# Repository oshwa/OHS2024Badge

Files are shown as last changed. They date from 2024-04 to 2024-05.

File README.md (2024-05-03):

# OHS 2024 Badge

Hack your OHS 2024 Badge! There will be a hacking station during the summit to modify the badge code (we'll supply some programmers). If you want to add some of your own hardware to the badge, bring some tools and components to make your own SAO!

## Badge Overview

The front and back of the badge:

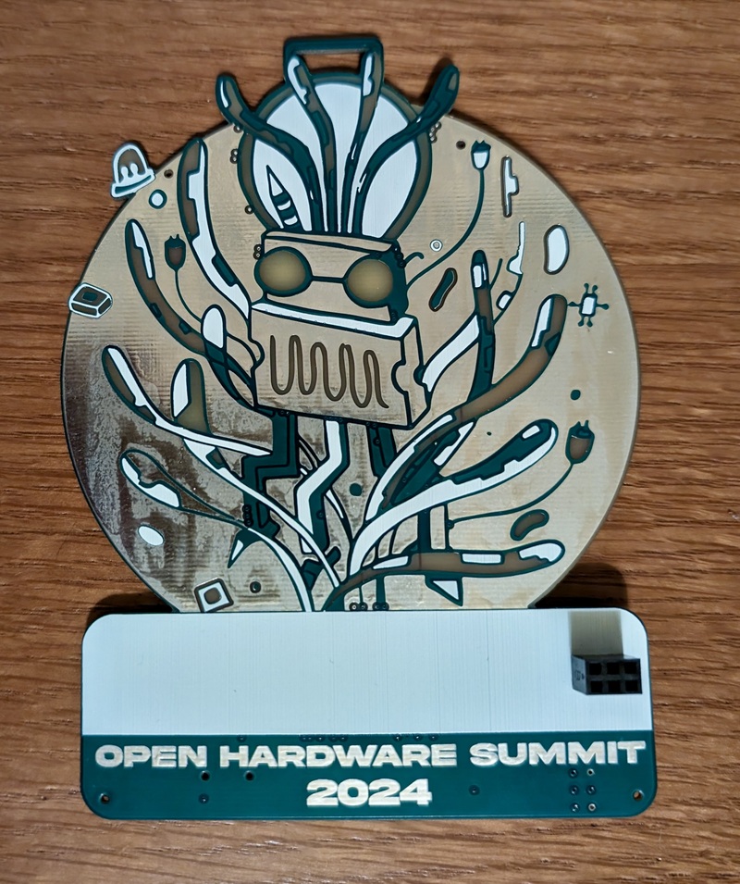
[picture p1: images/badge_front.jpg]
Front view of Open Hardware Summit 2024 Badge PCB.

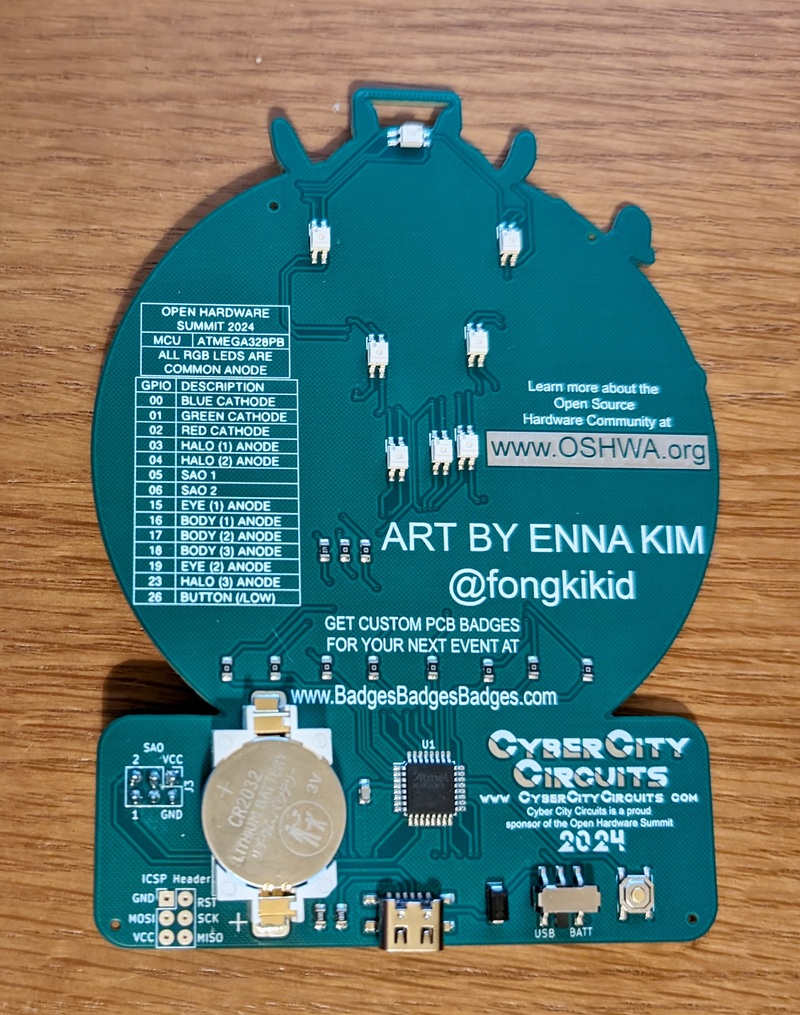
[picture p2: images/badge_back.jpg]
Back view of Open Hardware Summit 2024 Badge PCB.


The badge features some amazing art by [Enna Kim](https://www.instagram.com/fongkikid/) and was created by [Cyber City Circuits](https://cybercitycircuits.com/).

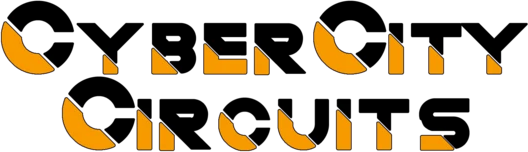
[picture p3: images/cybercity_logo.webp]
Cyber City Circuits Logo.


The badge features:

- Eight RGB LEDs that light up the eyes, ring and body of the lil' guy
- Preloaded LED animations - use the push button to cycle through them all!
- Switch between battery and USB power
- [SAO connector](https://hackaday.io/project/175182-simple-add-ons-sao) with power and two GPIO pins for badge addons!

## Getting Started

### Choose Your Programmer

The badge is compatible with Arduino IDE. However, there is no USB data connection so the badge has to have an external programmer to modify the code on the microcontroller. An easy programmer to use is the [USBtinyISP](https://learn.adafruit.com/usbtinyisp/overview) which is affordable and open source. Here is a version of the board sold on Amazon:

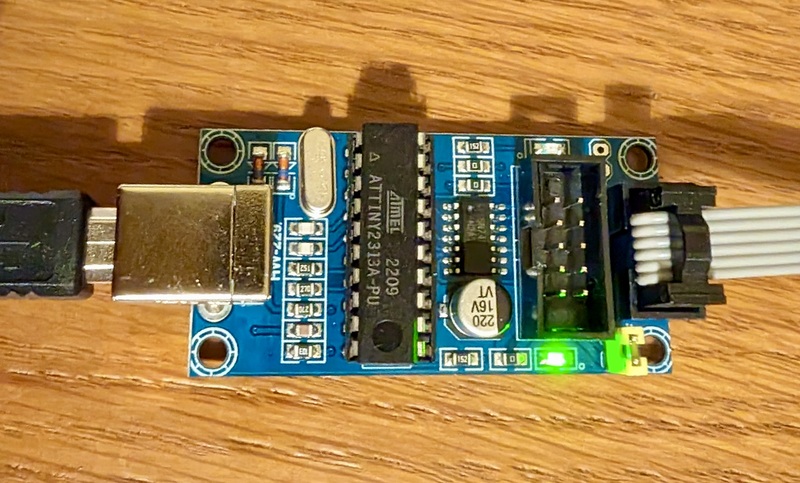
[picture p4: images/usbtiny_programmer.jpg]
USBtinyISP programmer.


You may need to install drivers on Windows: [https://learn.adafruit.com/usbtinyisp/download](https://learn.adafruit.com/usbtinyisp/download)

### Setup Arduino IDE

The board uses [MiniCore](https://github.com/MCUdude/MiniCore) with the [Arduino IDE](https://www.arduino.cc/en/software). Follow these instructions to install MiniCore:
[https://github.com/MCUdude/MiniCore?tab=readme-ov-file#how-to-install](https://github.com/MCUdude/MiniCore?tab=readme-ov-file#how-to-install)

Clone this repository and open [OHS2024Badge.ino](OHS2024Badge.ino) in the Arduino IDE.

Connect the USBtinyISP programmer to your computer.

From the *Tools* menu select:

- Board: -> MiniCore -> ATmega328
- Clock: -> Internal 8 MHz
- Variant: -> 328PB
- Programmer: -> USBtinyISP

**NOTE**: You do not need to set the port, the programmer will be seen as a USB device by the operating system.

Build the code by selecting from the menu *Sketch -> Verify/Compile*. If all goes well, the code should compile without any errors.

### Upload With a Programmer

Now for the tricky part: We have to hold the programmer spring-loaded (pogo) pins directly onto the exposed ICSP pads on the back of the Badge. Make sure the pins from the programmer line up with the pads on the badge. There are often labels written directly on the PCBs that tell you which pin is which. If the badge becomes powered by the programmer, you know the connection is being made properly. The following pictures show how the 2x3 pin header is arranged and how to hold spring-loaded pins directly onto the badge PCB:

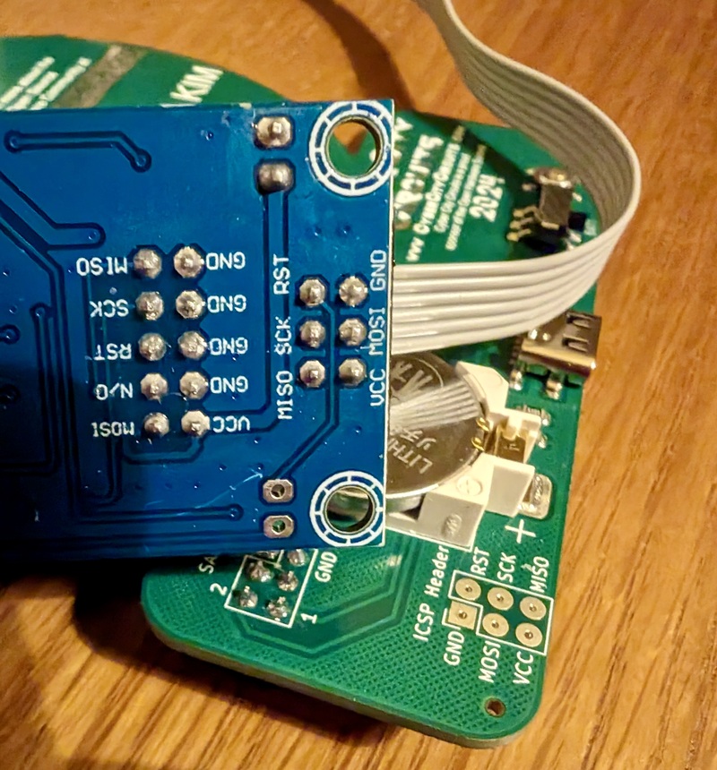
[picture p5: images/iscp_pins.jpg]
Pin labels on programmer and badge PCB.

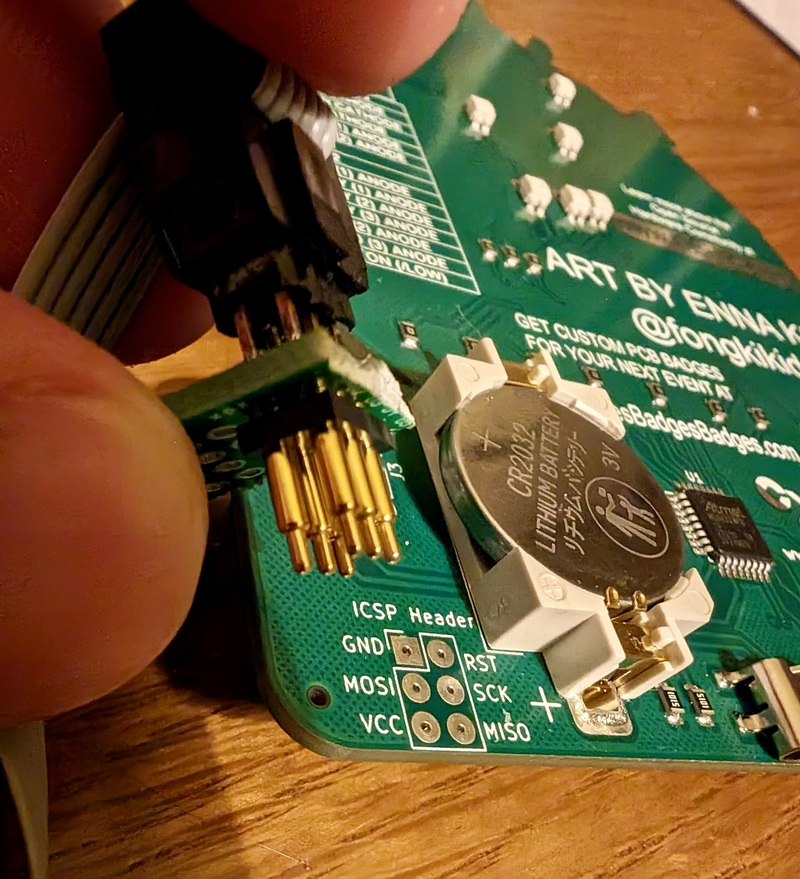
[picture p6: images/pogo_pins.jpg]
Close up of spring-loaded pogo pins.

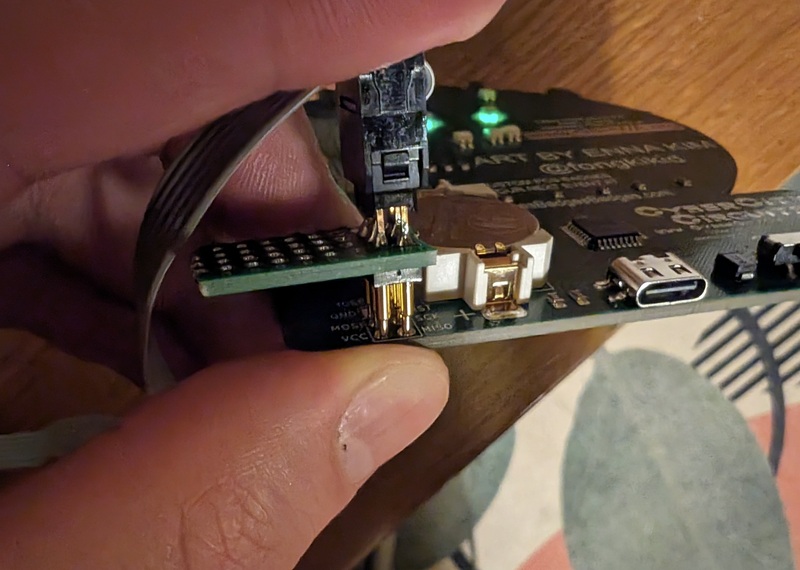
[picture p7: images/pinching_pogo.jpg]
Fingers holding spring-loaded pogo pins on badge.


While holding the pins directly onto the badge, in the Arduino IDE click the menu item *Sketch -> Upload Using Programmer* and wait for the upload process to finish. The upload progress is shown in the IDE Output.

There are easier ways to hold the pins to the badge, such as a clip or a custom jig to clamp the pogo pins. Bring your own if you have one handy!

## Modify the Code

The default code already loaded on the badge is available in the example folder: [examples/DefaultBadge/OHS2024BadgeDefault.ino](examples/DefaultBadge/OHS2024BadgeDefault.ino)

A simplified sample is provided in the main directory: [OHS2024Badge.ino](OHS2024Badge.ino).

You can modify it to make your own custom animations!

## Add an SAO

The [Simple Add-On (SAO) connector](https://hackaday.io/project/175182-simple-add-ons-sao) provides power and two GPIO pins for badge addons!

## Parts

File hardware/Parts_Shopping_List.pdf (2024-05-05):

Line | Description | Designators | Package | Qty | Vendor | Vendor PN
1 | Resistor, 5.1 k Ω | R1, R2 | 0805 | 2 | LCSC | C26023
2 | Resistor, 100 Ω | R4, R5, R10-R17 | 0805 | 10 | LCSC | C25277
3 | Resistor, 270 Ω | R6 | 0805 | 1 | LCSC | C25298
4 | Schottky Diode | D10 | SOD323F | 1 | LCSC | C369937
5 | LED, RGB, Reverse Mount | D1-D8 | PLCC-4 | 8 | Digikey | 1497-1257-1-ND
6 | Switch, Power | SW1 | SMT-6 | 1 | LCSC | C963207
7 | Button, Mode | SW2 | SMT-4 | 1 | LCSC | C480267
8 | Capacitor, 0.1 uF | C1 | 0805 | 1 | LCSC | C235732
9 | USB - Power Only USB-C | J1 | USB | 1 | LCSC | C2927027
10 | Battery Holder - CR2032 | BT1 | | 1 | LCSC | C964760
11 | ATMEGA328PB | U1 | SOIC14 | 1 | Digikey | ATMEGA328PB-AU-ND
12 | Battery, CR2032 | | | 1

# Open Hardware Summit 2024 Badge

# Shopping List

Cyber City Circuits - www.CyberCityCircuits.com

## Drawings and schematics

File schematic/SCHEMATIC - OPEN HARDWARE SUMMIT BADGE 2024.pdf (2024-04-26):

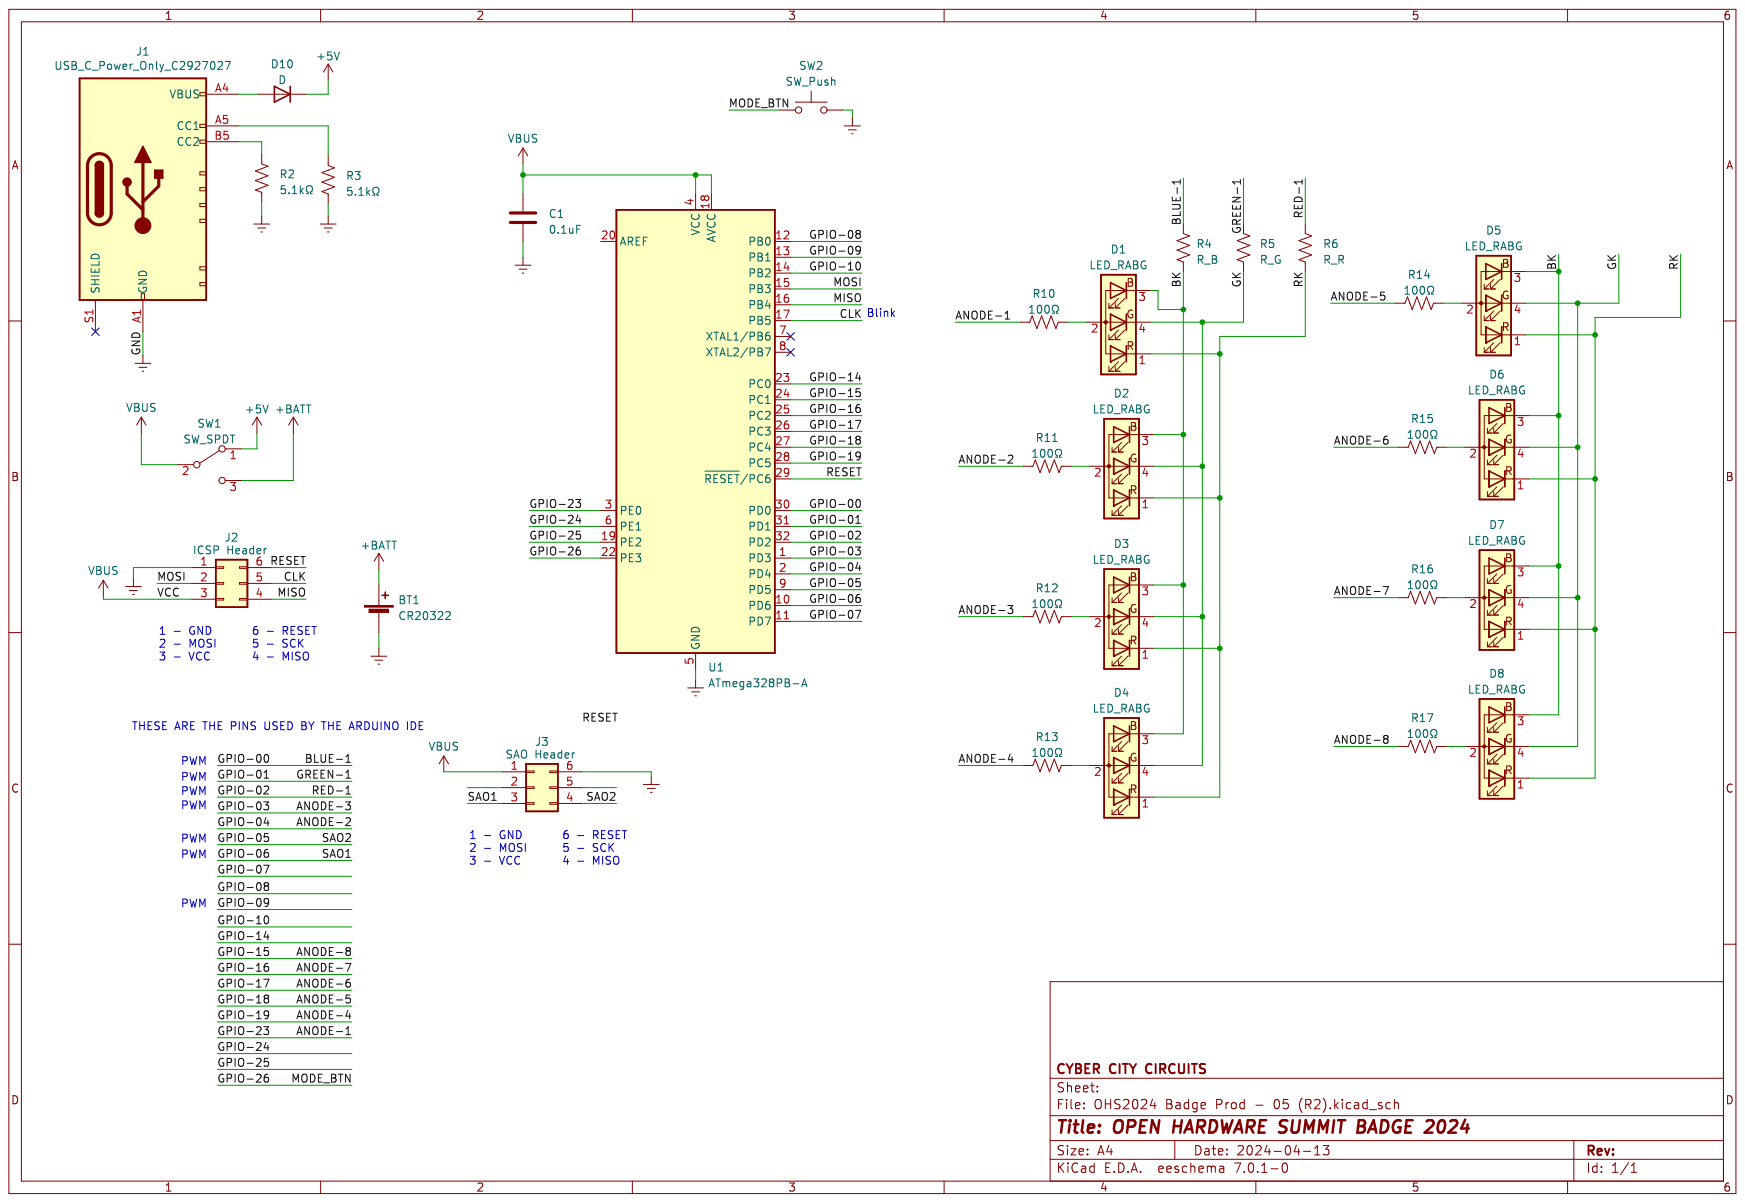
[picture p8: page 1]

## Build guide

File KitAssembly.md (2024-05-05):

# OHS 2024 Badge Kit Assembly
Some of the badges distributed at OHS 2024 came without electronic components, unfortunately. However, we've put together some parts kits for you to try assembling it yourself!
## Parts List

The original parts list for the badge can be found here: [hardware/Parts_Shopping_List.pdf](hardware/Parts_Shopping_List.pdf)

You should have received the following:
- 1x Battery Holder
- 1x Pushbutton
- 1x Slide Switch
- 1x SAO header
- 1x USB Type C connector
- 1-2x Diodes (you only need one, we tried to give you a spare)
- 8x LEDs (we have a few spares, but please be careful - you need 8)
- 2x ATMEGA328PB Microcontrollers (you only need one, we gave you a spare)
- 2x 0.1uF capacitors (short paper tape, parts are brown with silver ends. You only need one, we gave you a spare)
- 3x 270 ohm resistors (blue stripe on the paper tape. You only need one, we gave you a spare)
- 15x 100 ohm resistors (long paper tape. You only need 10, we gave you spares)
- 4x 5.1K ohm resistors (short paper tape. You only need two, we gave you spares)

Here's a photo of the parts you should have:
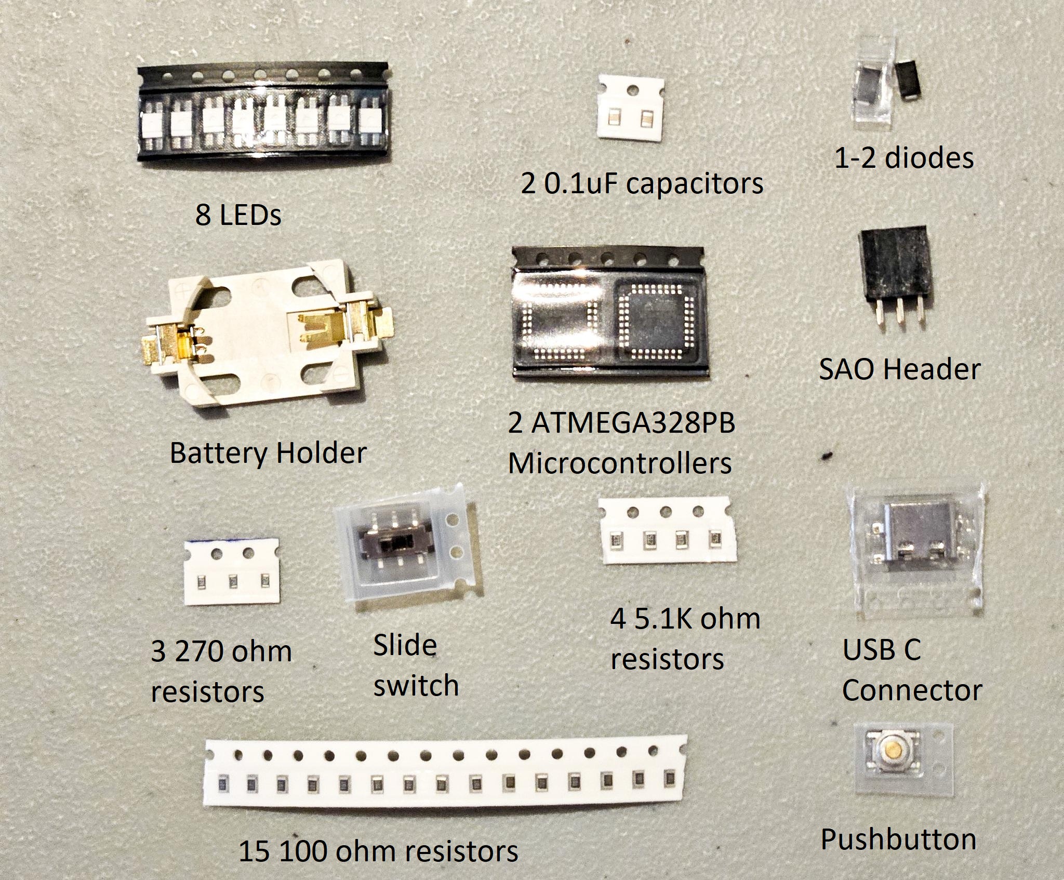
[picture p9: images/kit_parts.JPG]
Top view of the parts provided in the kit, with text labels for each part.


## Where the parts go
The diagram below shows where the parts go on the board:

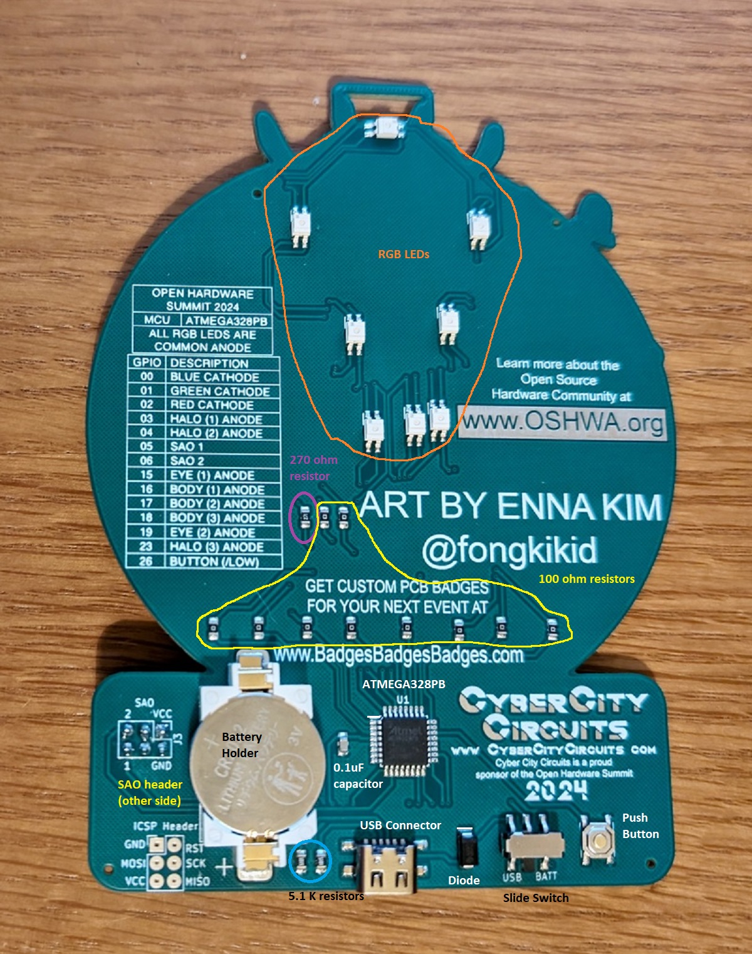
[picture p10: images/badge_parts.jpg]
Rear view of Open Hardware Summit 2024 Badge PCB, with different components circled to indicate their positions.


The biggest thing to be aware of is the mounting of the LEDs:
- We're using slightly different LEDs than were on the original boards, because they're much, much cheaper.
- The pins of the LEDs stick out straight from the body of the LED. You'll need to bend them down - this is towards the side of the LED with the clear lens. The tips of the pins should be about flush with the face of the LED.
- When you mount the LED to the board, note that one of the pins of the LED is chamfered (has a corner cut off). This pin should not be placed on the pad with the white stripe - it should be on the pin diagonally across from that.

LEDs before you bend them:

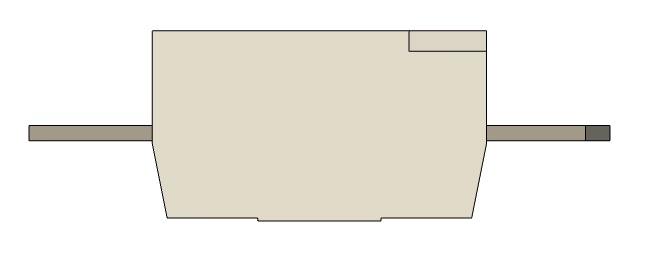
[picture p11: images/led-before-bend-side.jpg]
LED side view, before bending

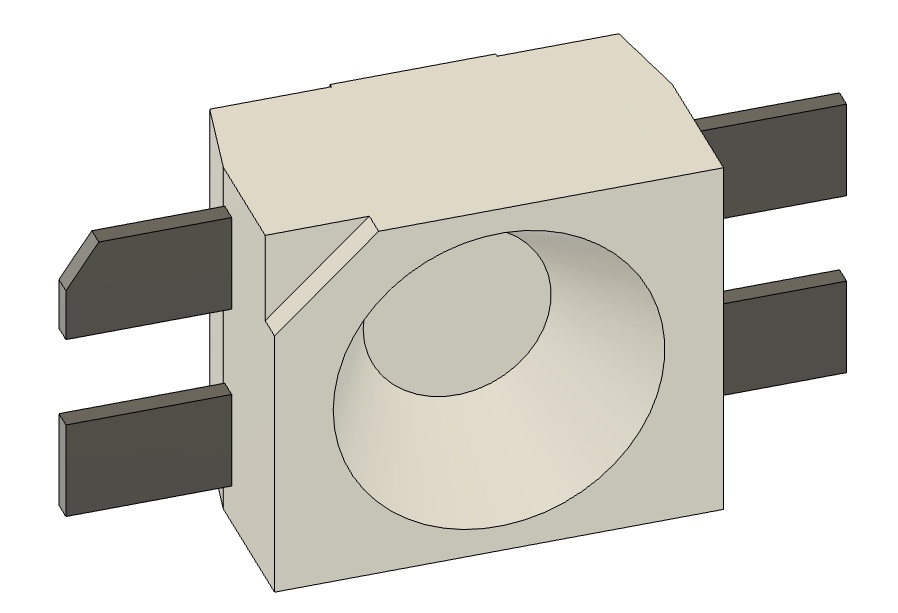
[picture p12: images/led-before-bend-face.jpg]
LED face, before bending


LEDs after you bend them:

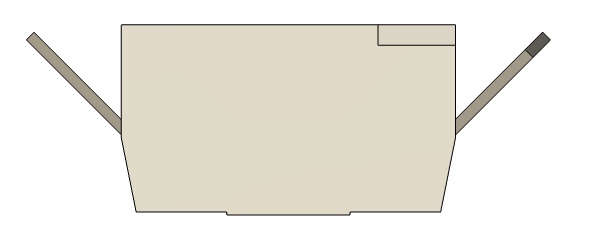
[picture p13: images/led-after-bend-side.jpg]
LED side view, after bending

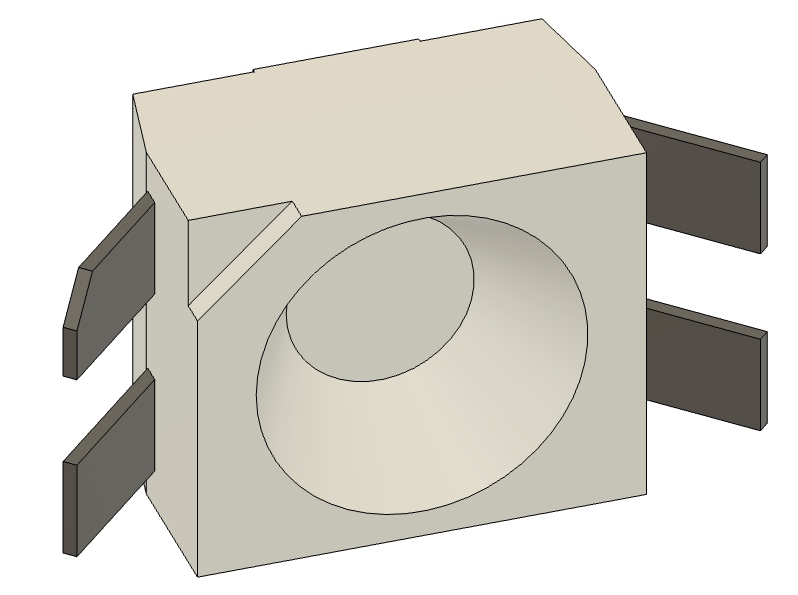
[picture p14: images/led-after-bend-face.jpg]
LED face, after bending


LED alignment on the board. White stripe circled in blue, chamfered pin circled in red:

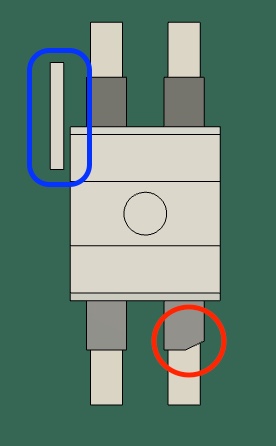
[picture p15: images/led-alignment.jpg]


Some other notes on placing the parts:
- The capacitors and resistors don't care which way they go on the board - there are two ways that they fit, and both work fine
- The diode is polarized. If you look at it from the right angle, you'll see a stripe on one side. This lines up with a white stripe on the board.
- The battery holder is polarized. One corner is chamfered (cut at an angle) - this is on the positive side. This lines up with the + side indicated on the PCB
- The pushbutton has 2 orientations that it will fit the pads on the board. Either of those orientations will work.
- The microcontroller has 4 ways that it will fit, but only one will work. There is an indented dot on the microcontroller - this lines up with the white stripe beside one of the pins on the PCB. Also, with the lanyard loop pointed away from you, the microcontroller should be mounted such that you can read the text.

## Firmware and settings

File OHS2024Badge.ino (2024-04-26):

/*
  Open Hardware Summit 2024
  Designed by Cyber City Circuits
  Twitter @MakeAugusta

  This board uses Minicore with the Arduino IDE:
  https://github.com/MCUdude/MiniCore?tab=readme-ov-file#how-to-install

  Board: ATMEGA328
  Clock: Internal 8MHz
  Variant: 328PB
  Port: Comm Port used for your programmer
  Programmer: Arduino as ISP

  Pin LEDs:
  Anode 1: 23 - Head Ring Right
  Anode 2: 04 - Head Ring Top
  Anode 3: 03 - Head Ring L eft
  Anode 4: 19 - Eye Right
  Anode 5: 18 - Body Right
  Anode 6: 17 - Body Center
  Anode 7: 16 - Body Left
  Anode 8: 15 - Eye Left

  Pin RGB for LED 1-4:
  Blue:  00
  Green: 01
  Red:   02

  Button: 26 (Active Low)

  SAO GPIO:
  SAO 1: 06
  SAO 2: 05

*/

// Pin Definitions
// ===============

#define MODE_BUTTON_PIN 26

#define LED_PIN_HEAD_RIGHT 23
#define LED_PIN_HEAD_TOP 4
#define LED_PIN_HEAD_LEFT 3

#define LED_PIN_EYE_RIGHT 19
#define LED_PIN_EYE_LEFT 15

#define LED_PIN_BODY_RIGHT 18
#define LED_PIN_BODY_CENTER 17
#define LED_PIN_BODY_LEFT 16

#define COLOR_PIN_RED 2
#define COLOR_PIN_GREEN 1
#define COLOR_PIN_BLUE 0

#define SAO_PIN_1 6
#define SAO_PIN_2 5

// LED Animation settings
//   - Continuous transitions between low and high brightness
//   - Pressing the button cycles between modes:
//     - Mode 0: Green eyes
//     - Mode 1: Blueish-white body
//     - Mode 2: Red halo above head
// ==================================================

// Used to ensure button is triggered only once when pressed
#define DEBOUNCE_MAX_STEPS 2

// Cycle through this many modes with a button press
#define NUM_MODES 3

// This integer changes how fast the LEDs change brightness
// slow: 1, fast: 40
#define ANIMATION_SPEED 2
#define ANIMATION_MIN_BRIGHTNESS 10
#define ANIMATION_MAX_BRIGHTNESS 180

// polling timer at 50 milliseconds (20 times per second)
#define TIMER_STEP_MS 50
uint32_t timer_prev = 0;

void setup() {
    // Setup pins
    ConfigurePins();

    // Start with eyes on
    TurnOffBodyLEDs();
    TurnOffHeadLEDs();
    TurnOnEyeLEDs();

    // Start with green
    SetColor(0, 200, 50);

    // timer begin
    timer_prev = millis();
}

void loop() {
    // run timer
    uint32_t now = millis();
    uint32_t elapsed = now - timer_prev;
    if (elapsed >= TIMER_STEP_MS) {
        // advance timer
        timer_prev = timer_prev + TIMER_STEP_MS;

        // get button input
        bool button_pressed = ButtonDebounce(digitalRead(MODE_BUTTON_PIN));

        // Return mode value 0, 1, or 2, cycled by button press
        // LEDs are turned on and off depending on which mode is activated
        int mode = HandleButtonPress(button_pressed);

        // Animate color based on current mode
        AnimateFadeSequence(mode);
    }
}

void ConfigurePins() {
    // PWM LED cathodes to HIGH (no color)
    pinMode(COLOR_PIN_RED, OUTPUT);
    pinMode(COLOR_PIN_GREEN, OUTPUT);
    pinMode(COLOR_PIN_BLUE, OUTPUT);
    digitalWrite(COLOR_PIN_RED, HIGH);
    digitalWrite(COLOR_PIN_GREEN, HIGH);
    digitalWrite(COLOR_PIN_BLUE, HIGH);

    // LED Anodes to LOW
    pinMode(LED_PIN_HEAD_RIGHT, OUTPUT);
    pinMode(LED_PIN_HEAD_TOP, OUTPUT);
    pinMode(LED_PIN_HEAD_LEFT, OUTPUT);
    digitalWrite(LED_PIN_HEAD_RIGHT, LOW);
    digitalWrite(LED_PIN_HEAD_TOP, LOW);
    digitalWrite(LED_PIN_HEAD_LEFT, LOW);

    pinMode(LED_PIN_EYE_RIGHT, OUTPUT);
    pinMode(LED_PIN_EYE_LEFT, OUTPUT);
    digitalWrite(LED_PIN_EYE_RIGHT, LOW);
    digitalWrite(LED_PIN_EYE_LEFT, LOW);

    pinMode(LED_PIN_BODY_RIGHT, OUTPUT);
    pinMode(LED_PIN_BODY_CENTER, OUTPUT);
    pinMode(LED_PIN_BODY_LEFT, OUTPUT);
    digitalWrite(LED_PIN_BODY_RIGHT, LOW);
    digitalWrite(LED_PIN_BODY_CENTER, LOW);
    digitalWrite(LED_PIN_BODY_LEFT, LOW);

    // Button mode
    pinMode(MODE_BUTTON_PIN, INPUT_PULLUP);
}

void AnimateFadeSequence(int mode) {
    // animation state
    static int brightness = 255;
    static int anim_state = -1;

    // set color based on mode
    int color_red = 0;
    int color_green = 0;
    int color_blue = 0;
    switch (mode) {
        case 0:
            // Eye color
            color_red = 0;
            color_green = 255;
            color_blue = 0;
            break;

        case 1:
            // Body color
            color_red = 0;
            color_green = 0;
            color_blue = 255;
            break;

        case 2:
            // Head color
            color_red = 255;
            color_green = 0;
            color_blue = 0;
            break;

        default:
            break;
    }

    // update brightness
    brightness += anim_state * ANIMATION_SPEED;
    // reverse direction
    if (brightness > ANIMATION_MAX_BRIGHTNESS) {
        anim_state = -1;
        brightness = ANIMATION_MAX_BRIGHTNESS;
    } else if (brightness < ANIMATION_MIN_BRIGHTNESS) {
        anim_state = 1;
        brightness = ANIMATION_MIN_BRIGHTNESS;
    }

    // set color with brightness
    SetColorBrightness(color_red, color_green, color_blue, brightness);
}

int HandleButtonPress(bool button_pressed) {
    static int current_mode = 0;

    if (button_pressed) {
        // button pressed: go to next mode
        current_mode++;
        if (current_mode >= NUM_MODES) {
            current_mode = 0;
        }
        // transition state
        switch (current_mode) {
            case 0:
                // Transition to Eyes
                TurnOffBodyLEDs();
                TurnOffHeadLEDs();
                TurnOnEyeLEDs();
                break;

            case 1:
                // Transition to Body
                TurnOffEyeLEDs();
                TurnOffHeadLEDs();
                TurnOnBodyLEDs();
                break;

            case 2:
                // Transition to Head
                TurnOffBodyLEDs();
                TurnOffEyeLEDs();
                TurnOnHeadLEDs();
                break;

            default:
                break;
        }
    }

    return current_mode;
}

void SetColorBrightness(int32_t red, int32_t green, int32_t blue, int32_t brightness) {
    red = 255 - (constrain(red, 0, 255) * constrain(brightness, 0, 255)) / 255;
    green = 255 - (constrain(green, 0, 255) * constrain(brightness, 0, 255)) / 255;
    blue = 255 - (constrain(blue, 0, 255) * constrain(brightness, 0, 255)) / 255;
    analogWrite(COLOR_PIN_RED, red);
    analogWrite(COLOR_PIN_GREEN, green);
    analogWrite(COLOR_PIN_BLUE, blue);
}

void SetColor(int red, int green, int blue) {
    red = 255 - constrain(red, 0, 255);
    green = 255 - constrain(green, 0, 255);
    blue = 255 - constrain(blue, 0, 255);
    analogWrite(COLOR_PIN_RED, red);
    analogWrite(COLOR_PIN_GREEN, green);
    analogWrite(COLOR_PIN_BLUE, blue);
}

void TurnOnHeadLEDs() {
    digitalWrite(LED_PIN_HEAD_RIGHT, HIGH);
    digitalWrite(LED_PIN_HEAD_TOP, HIGH);
    digitalWrite(LED_PIN_HEAD_LEFT, HIGH);
}

void TurnOffHeadLEDs() {
    digitalWrite(LED_PIN_HEAD_RIGHT, LOW);
    digitalWrite(LED_PIN_HEAD_TOP, LOW);
    digitalWrite(LED_PIN_HEAD_LEFT, LOW);
}

void TurnOnEyeLEDs() {
    digitalWrite(LED_PIN_EYE_RIGHT, HIGH);
    digitalWrite(LED_PIN_EYE_LEFT, HIGH);
}
void TurnOffEyeLEDs() {
    digitalWrite(LED_PIN_EYE_RIGHT, LOW);
    digitalWrite(LED_PIN_EYE_LEFT, LOW);
}

void TurnOnBodyLEDs() {
    digitalWrite(LED_PIN_BODY_RIGHT, HIGH);
    digitalWrite(LED_PIN_BODY_CENTER, HIGH);
    digitalWrite(LED_PIN_BODY_LEFT, HIGH);
}
void TurnOffBodyLEDs() {
    digitalWrite(LED_PIN_BODY_RIGHT, LOW);
    digitalWrite(LED_PIN_BODY_CENTER, LOW);
    digitalWrite(LED_PIN_BODY_LEFT, LOW);
}

bool ButtonDebounce(int button_input) {
    static int button_prev = HIGH;
    static int button_steps = 0;

    bool button_pressed = false;
    if (button_prev == HIGH) {
        if (button_input == LOW) {
            button_steps++;
            if (button_steps > DEBOUNCE_MAX_STEPS) {
                button_pressed = true;
                button_prev = LOW;
                button_steps = 0;
            }
        } else if (button_steps > 0) {
            button_steps--;
        }
    } else {
        if (button_input == HIGH) {
            button_steps++;
            if (button_steps > DEBOUNCE_MAX_STEPS) {
                button_prev = HIGH;
                button_steps = 0;
            }
        } else if (button_steps > 0) {
            button_steps--;
        }
    }

    return button_pressed;
}

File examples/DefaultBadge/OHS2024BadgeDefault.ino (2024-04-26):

/*
  Open Hardware Summit 2024
  Designed by Cyber City Circuits
  Twitter @MakeAugusta

  This board uses Minicore with the Arduino IDE:
  https://github.com/MCUdude/MiniCore?tab=readme-ov-file#how-to-install

  Board: ATMEGA328
  Clock: Internal 8MHz
  Variant: 328PB
  Port: Comm Port used for your programmer
  Programmer: Arduino as ISP

  Pin LEDs:
  Anode 1: 23 - Head Ring Right
  Anode 2: 04 - Head Ring Top
  Anode 3: 03 - Head Ring Left
  Anode 4: 19 - Eye Right
  Anode 5: 18 - Body Right
  Anode 6: 17 - Body Center
  Anode 7: 16 - Body Left
  Anode 8: 15 - Eye Left

  Pin RGB for LED 1-4:
  Blue:  00
  Green: 01
  Red:   02

  Button: 26 (Active Low)

  SAO GPIO:
  SAO 1: 06
  SAO 2: 05

*/

// colors
int white[]  = {255, 255, 255};
int red[]    = {255,   0,   0};
int cyan[]   = {255,  65,   0};
int orange[] = {180,  20,  20};
int yellow[] = {255,  65,   0};
int purple[] = { 20,   0, 255};
int green[]  = {  0, 255,   0};
int blue[]   = {  0,   0, 255};
int pink[]   = { 20,   0, 255};

// Pin Assignments
int LED_Count = 8;
int Anodes[8] = {23, 4, 3, 19, 18, 17, 16, 15};
int Mode_Btn = 26;
int Blue = 0;   // PWM Only
int Red = 2;    // PWM Only
int Green = 1;  // PWM Only
int RandomSeedPin = 14;

int no_1[] = {Anodes[0], Anodes[1], Anodes[2]};  // Ring
int no_2[] = {Anodes[3], Anodes[7], Anodes[7]};  // Eyes
int no_3[] = {Anodes[4], Anodes[5], Anodes[6]};  // Body

// Set Colors as Class Objects

long my_timer;
long mydelay = 100;

int Mode = 4;
int Program = 10;
int digit = 0;

int CurrentColor[3] = {0, 0, 0};
int colorwheel = 0;
int strand = 0;
int fade = 0;

void setup() {
    pinMode(Mode_Btn, INPUT_PULLUP);
    pinMode(Blue, OUTPUT);
    pinMode(Red, OUTPUT);
    pinMode(Green, OUTPUT);
    digitalWrite(Blue, HIGH);
    digitalWrite(Red, HIGH);
    digitalWrite(Green, HIGH);
    for (int i = 0; i < LED_Count; i++) {
        pinMode(Anodes[i], OUTPUT);
        digitalWrite(Anodes[i], LOW);
    }

    randomSeed(analogRead(RandomSeedPin));

    // POST
    if (digitalRead(Mode_Btn) == LOW) {
        delay(100);
        POST();
    }

    BootUp();

    for (int x = 0; x < 2; x++) {
        CurrentColor[x] = green[x];
    }
}

void loop() {
    if (digitalRead(Mode_Btn) == LOW) {
        delay(200);
        reset();
        Mode++;
        if (Mode > 8) {
            Mode = 0;
        }

        switch (Mode) {
            case 0:  // Red Cycle
                Program = 0;
                CurrentColor[0] = 255;  // red
                CurrentColor[1] = 0;    // green
                CurrentColor[2] = 0;    // blue
                break;
            case 1:  // Green Cycle
                Program = 0;
                CurrentColor[0] = 0;
                CurrentColor[1] = 255;
                CurrentColor[2] = 0;
                break;
            case 2:
                Program = 0;  // Blue Cycle
                CurrentColor[0] = 0;
                CurrentColor[1] = 0;
                CurrentColor[2] = 255;
                break;
            case 3:
                Program = 0;  // Orange Cycle
                CurrentColor[0] = 180;
                CurrentColor[1] = 20;
                CurrentColor[2] = 20;
                break;
            case 4:
                Program = 10;  // Set Random Colors
                break;
            case 5:
                Program = 20;  // Fast Fireworks
                // CurrentColor[0] = random(250);
                // CurrentColor[1] = random(250);
                // CurrentColor[2] = random(250);
                break;
            case 6:
                Program = 30;  // Fireworks
                break;
            case 7:
                Program = 40;  // Twinkle
                break;
            case 8:
                Program = 50;  // Strand Test Color Fade
                break;
        }
    }

    switch (Program) {
        case 0:  // Set up timer for case 1
            mydelay = 100;
            my_timer = millis() + mydelay;
            Program = 1;
            break;
        case 1:  // Cycle through numbers on badge with random colors
            // set first set
            // setColor(random(255), random(255), random(255));
            setColor(CurrentColor[0], CurrentColor[1], CurrentColor[2]);
            if (digit == 0) {
                digitalWrite(no_1[0], HIGH);
                digitalWrite(no_1[1], HIGH);
                digitalWrite(no_1[2], HIGH);
                if (millis() > my_timer) {
                    my_timer = millis() + mydelay;
                    digitalWrite(no_1[0], LOW);
                    digitalWrite(no_1[1], LOW);
                    digitalWrite(no_1[2], LOW);
                    digit++;
                }
            }
            if (digit == 1) {
                digitalWrite(no_2[0], HIGH);
                digitalWrite(no_2[1], HIGH);
                digitalWrite(no_2[2], HIGH);
                if (millis() > my_timer) {
                    my_timer = millis() + mydelay;
                    digitalWrite(no_2[0], LOW);
                    digitalWrite(no_2[1], LOW);
                    digitalWrite(no_2[2], LOW);
                    digit++;
                }
            }
            if (digit == 2) {
                digitalWrite(no_3[0], HIGH);
                digitalWrite(no_3[1], HIGH);
                digitalWrite(no_3[2], HIGH);
                if (millis() > my_timer) {
                    my_timer = millis() + mydelay;
                    digitalWrite(no_3[0], LOW);
                    digitalWrite(no_3[1], LOW);
                    digitalWrite(no_3[2], LOW);
                    digit = 0;
                }
            }
            break;

        case 20:  // Set up timer for case 1
            fastfirework();
            break;
        case 30:
            firework();
            break;
        case 40:
            twinkle();
            break;
        case 50:
            strandtest();
            break;
        case 10:
            // set first set
            setColor(random(5, 250), random(5, 175), random(100, 250));
            digitalWrite(no_1[0], HIGH);
            digitalWrite(no_1[1], HIGH);
            digitalWrite(no_1[2], HIGH);
            delay(150);
            digitalWrite(no_1[0], LOW);
            digitalWrite(no_1[1], LOW);
            digitalWrite(no_1[2], LOW);

            setColor(random(5, 250), random(5, 175), random(100, 250));
            digitalWrite(no_2[0], HIGH);
            digitalWrite(no_2[1], HIGH);
            digitalWrite(no_2[2], HIGH);
            delay(150);
            digitalWrite(no_2[0], LOW);
            digitalWrite(no_2[1], LOW);
            digitalWrite(no_2[2], LOW);

            setColor(random(5, 250), random(5, 175), random(100, 250));
            digitalWrite(no_3[0], HIGH);
            digitalWrite(no_3[1], HIGH);
            digitalWrite(no_3[2], HIGH);
            delay(150);
            digitalWrite(no_3[0], LOW);
            digitalWrite(no_3[1], LOW);
            digitalWrite(no_3[2], LOW);
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

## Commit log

2024-04-30 Added pcb hardware source (kicad)
    [OHS2024 Badge Release-B_Cu.gbr, OHS2024 Badge Release-B_Mask.gbr, OHS2024 Badge Release-B_Paste.gbr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]
2024-05-03 Add link to windows drivers
2024-05-03 Adding first draft of kit assembly documentation
2024-05-03 Adding diagrams of how to bend LED pins
2024-05-03 Correcting flow of page
2024-05-04 Adds LED Alignment diagram
2024-05-04 Page flow adjustment
